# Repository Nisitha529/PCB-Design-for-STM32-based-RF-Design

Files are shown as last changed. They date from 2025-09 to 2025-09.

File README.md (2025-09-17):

# PCB-Design-for-STM32-based-RF-Design
This PCB board design is a USB-powered platform combining an STM32L432 Cortex-M4 microcontroller and an nRF24L01+ 2.4GHz transceiver. The board is designed with a focus on power delivery and signal integrity. Power is supplied via a USB Micro-B connector and regulated down to 3.3V by an XC6206 LDO, with attention paid to in-rush current limits for USB compliance. The USB data lines are protected against electrostatic discharge (ESD) by a dedicated USBLC6-2SC6 chip. The nRF24 module features a full impedance-matching network and a passive antenna circuit, ensuring optimal RF performance. The board includes a 10-pin ARM Serial Wire Debug (SWD) header for programming and debugging, status LEDs, and a crystal oscillator for the radio module.

## Power Regulation and USB Interface
The 5V supply from the USB port is first passed through a 100mA fuse for overcurrent protection, safeguarding the host port. A ferrite bead filters high-frequency noise from the power line. The core of the power circuit is an XC6206 low-dropout (LDO) regulator, which efficiently converts the 5V input to a stable 3.3V output, capable of supplying up to 200mA. Input and output capacitors ensure voltage stability and are carefully sized to limit in-rush current upon connection, ensuring compliance with the USB specification.

For the data interface, the USB D+ and D- lines are routed directly from the connector through a USBLC6-2SC6 ESD protection chip. This component is critical for shielding the sensitive microcontroller pins from electrostatic discharge, a common cause of failure in USB-connected devices. The design foregoes reverse polarity protection as the physical keying of the standardized USB connector makes incorrect insertion impossible.

Power Regulation and USB Interface Circuit Diagram

## Power Decoupling and Debug Interface
The board features a robust power delivery network for the microcontroller, utilizing multiple decoupling capacitors (a 1µF and three 100nF) on the +3.3V rail to ensure stable operation by filtering high and low-frequency noise. For programming and debugging, a standard 10-pin ARM Serial Wire Debug (SWD) connector is implemented. This interface provides access to the essential SWDIO and SWCLK signals, a connection to the NRST (Reset) line, and is powered by the board's +3.3V supply. An optional capacitor on the NRST line is noted to safeguard against potential parasitic resets, enhancing the board's stability.

Power Decoupling and Debug Interface Circuit Diagram

## nRF24L01+ Transceiver and RF Circuitry
The wireless core of the board is built around the nRF24L01+ transceiver module. It is connected to the microcontroller via a dedicated SPI bus (MOSI, MISO, SCK) and controlled using chip select (CS), chip enable (CE), and interrupt (IRQ) lines. Local power decoupling is ensured by a bank of 10nF capacitors. For RF performance, an impedance matching network is implemented between the module's antenna outputs (ANT1/ANT2) and the SMA connector. This network, consisting of inductors (L1-L3) and capacitors (C15-C18), transforms the output impedance for efficient power transfer to the passive antenna. A 16MHz crystal oscillator with its associated load capacitors (C13, C14) and a 1MΩ bias resistor (R5) provides the critical reference clock for the operation.
nRF24L01+ Transceiver and RF Circuitry Diagram

PCB Routing Diagram

## 3D View of the Final PCB Design
### Front View

3D Preview Front View

### Backward View

3D Preview Backward View

3D Preview 3

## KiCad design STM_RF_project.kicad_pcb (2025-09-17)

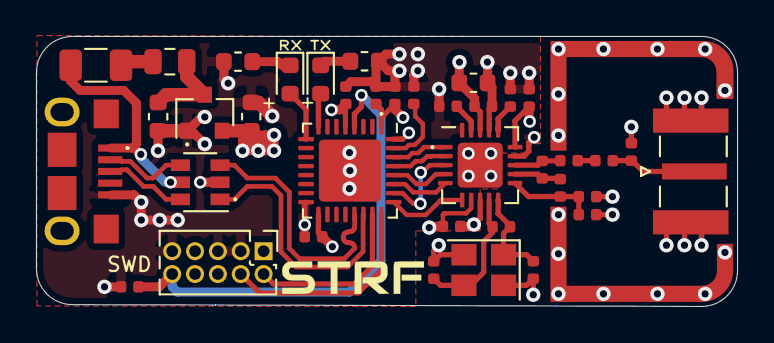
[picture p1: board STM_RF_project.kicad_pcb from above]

Board: 4 copper layers, 39.0 x 15.0 mm, 38 parts (0 on the bottom side), 32 nets.

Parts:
C1, C2, C8: 10u; C_0603_1608Metric
C3, C5, C6, C7: 100n; C_0402_1005Metric
C4: 1u; C_0402_1005Metric
C9, C10, C11: 10n; C_0402_1005Metric
C12: 33n; C_0402_1005Metric
C13, C14: 12p; C_0402_1005Metric
C15: 1p5; C_0402_1005Metric
C16: 1p; C_0402_1005Metric
C17: 2n2; C_0402_1005Metric
C18: 4p7; C_0402_1005Metric
D1: GR; LED_0603_1608Metric
D2: YE; LED_0603_1608Metric
F1: 100mA; Fuse_1206_3216Metric
FB1: 100 @ 100MHz; L_0805_2012Metric
J1: USB_B_Micro; 101181930001LF
J2: SMA; SMA_Samtec_SMA-J-P-X-ST-EM1_EdgeMount
J3: ARM 10pin; PinHeader_2x05_P1.27mm_Vertical
L1: 3n9; L_0402_1005Metric
L2: 8n2; L_0402_1005Metric
L3: 2n7; L_0402_1005Metric
R1: 2k2; R_0402_1005Metric
R2, R3: 2k2; R_0603_1608Metric
R4: 22k; R_0402_1005Metric
R5: 1M; R_0402_1005Metric
U1: XC6206P332MR; SOT-23
U2: USBLC6-2SC6; SOT-23-6
U3: STM32L432KBU6; QFN-32-1EP_5x5mm_P0.5mm_EP3.45x3.45mm
U4: nRF24L01P; QFN-20-1EP_4x4mm_P0.5mm_EP2.5x2.5mm
Y1: 16MHz; Crystal_SMD_3225-4Pin_3.2x2.5mm

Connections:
+3V3: C2.1, C4.1, C5.1, C6.1, C7.1, C8.1, C9.1, C10.1, C11.1, J3.1, U1.2, U3.1, U3.5, U3.17, U4.7, U4.15, U4.18
+5V: F1.2, J1.1, U2.5
GND: C1.2, C2.2, C3.2, C4.2, C5.2, C6.2, C7.2, C8.2, C9.2, C10.2, C11.2, C12.2, C13.2, C14.2, C16.1, C17.1, C18.1, J1.5, J2.2, J3.3, J3.5, J3.9, R1.2, R2.2, R3.2, R4.2, U1.1, U2.2, U3.16, U3.32, U3.33, U4.8, U4.14, U4.17, U4.20, U4.21, Y1.2, Y1.4
NRF_ANT1: L2.2, L3.2, U4.12
NRF_ANT2: L1.1, L2.1, U4.13
NRF_CE: U3.30, U4.1
NRF_IRQ: U3.25, U4.6
NRF_VDD_PA: C17.2, C18.2, L3.1, U4.11
NRF_XC1: C13.1, R5.2, U4.10, Y1.1
NRF_XC2: C14.1, R5.1, U4.9, Y1.3
NRST: C3.1, J3.10, U3.4
unnamed: C1.1, FB1.1, U1.3
unnamed: C12.1, U4.19
unnamed: C15.1, C16.2, J2.1
unnamed: C15.2, L1.2
unnamed: D1.1, R2.1
unnamed: D1.2, U3.9
unnamed: D2.1, R3.1
unnamed: D2.2, U3.8
unnamed: F1.1, FB1.2
unnamed: R1.1, U3.31
unnamed: R4.1, U4.16
SPI3_!CS: U3.29, U4.2
SPI3_MISO: U3.27, U4.5
SPI3_MOSI: U3.28, U4.4
SPI3_SCK: U3.26, U4.3
SWCLK: J3.4, U3.24
SWDIO: J3.2, U3.23
USB_CONN_D+: J1.3, U2.6
USB_CONN_D-: J1.2, U2.4
USB_D+: U2.1, U3.22
USB_D-: U2.3, U3.21
